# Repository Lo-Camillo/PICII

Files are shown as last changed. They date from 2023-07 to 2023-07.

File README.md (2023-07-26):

# Porta Medicamentos Inteligente
#### Grupo: Aryelle Siqueira, Giselle Pereira e Lohayne Camillo

Muitas pessoas enfrentam dificuldade  para lembrar de tomar seus medicamentos corretamente, especialmente quando têm que tomar múltiplos remédios diariamente.

O porta medicamentos inteligente surge como uma solução para ajudar a superar esses desafios.

## Como funciona?

O porta medicamentos possui 5 compartimentos para armazenar comprimidos. Através de um aplicativo, o usuário pode programar horários específicos para cada remédio, definindo qual compartimento será aberto.

O porta comprimidos possui um modo de programação no qual, ao selecionar um botão, o Wi-Fi será ativado para buscar diretamente do servidor os horários programados no aplicativo.

No horário programado, um alarme tocará, e ao pressionar um botão, o compartimento designado será aberto. Um visor mostrará a quantidade de comprimidos a serem ingeridos. Ao final da ingestão, ao pressionar o botão novamente, o compartimento girará para a próxima posição se houver outro remédio a ser tomado, caso contrário, retornará à posição inicial.

## Software

- [Código fonte e documentação do aplicativo](https://github.com/giselle-lab/porta-comprimidos).

- [Código fonte e documentação da API](https://github.com/AryelleSiqueira/pillbox-api.git).

- [Código fonte e documentação da ESP8266](https://github.com/AryelleSiqueira/porta-medicamentos-esp8266.git).

## Hardware

- [Documentação do hardware do projeto](Hardware_doc).

## Fotos & Vídeos

- [Acessar pasta de fotos e vídeos do projeto](Fotos&Videos).

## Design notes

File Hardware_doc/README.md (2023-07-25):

# Hardware

Para o hardware deste projeto, foi desenvolvida uma placa de circuito impresso em cobre para acomodar os componentes.

## Componentes

Os seguintes componentes foram usados:

- ESP8266 NodeMCU
- Motor de Passo 28BYJ-48 com Driver ULN2003
- Display OLED 0.96″ I2C - 128×64
- L7805C Regulador de Tensão 5V
- Push Button
- 3 resistores de 10k
- Buzzer
- Sockets
- Bateria 9V
- Placa de cobre

## Projeto no Eagle

A imagem a seguir demonstra o esquemático desenvolvido no software Eagle para confecção da placa. 

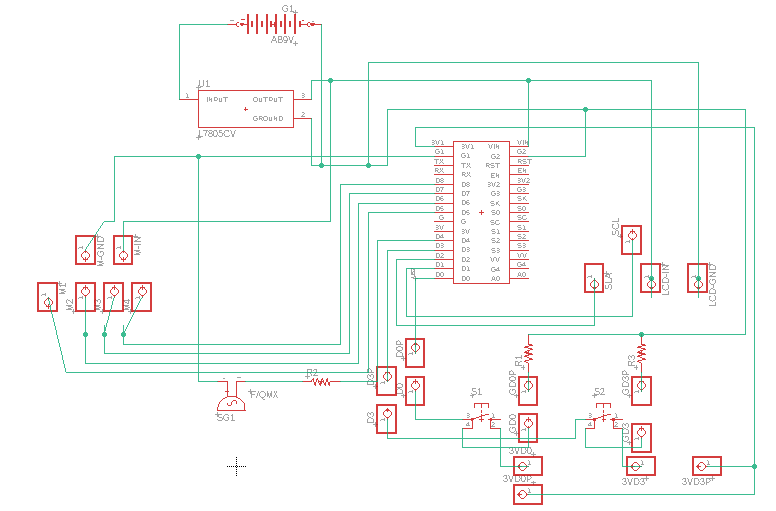
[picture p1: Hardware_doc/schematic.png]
Esquemático


Esta próxima imagem mostra o arquivo Board, onde mostra os componentes em seus respectivos lugares na placa:

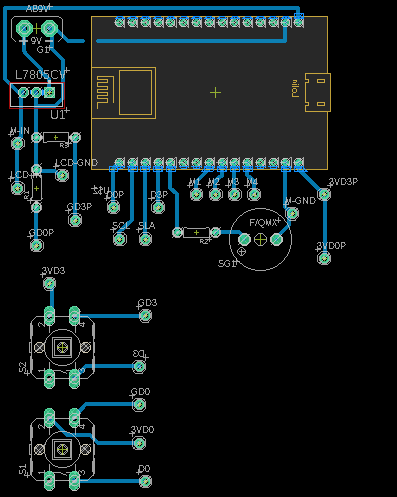
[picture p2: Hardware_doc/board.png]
Board


Alguns detalhes importantes a serem destacados:

- Na caixa desenvolvida, os botões e o visor estão posicionados voltados para fora, o que exigiu que eles fizessem parte de uma placa separada. Portanto, no esquemático, foram inseridos separadores onde, por meio de jumpers, as trilhas poderiam ser conectadas para interligar essas placas. O mesmo conceito se aplica aos conectores do motor.

## Caixa

Para o projeto, foi criada uma caixa em MDF. Na figura a seguir, podemos observar a estrutura dessa caixa.

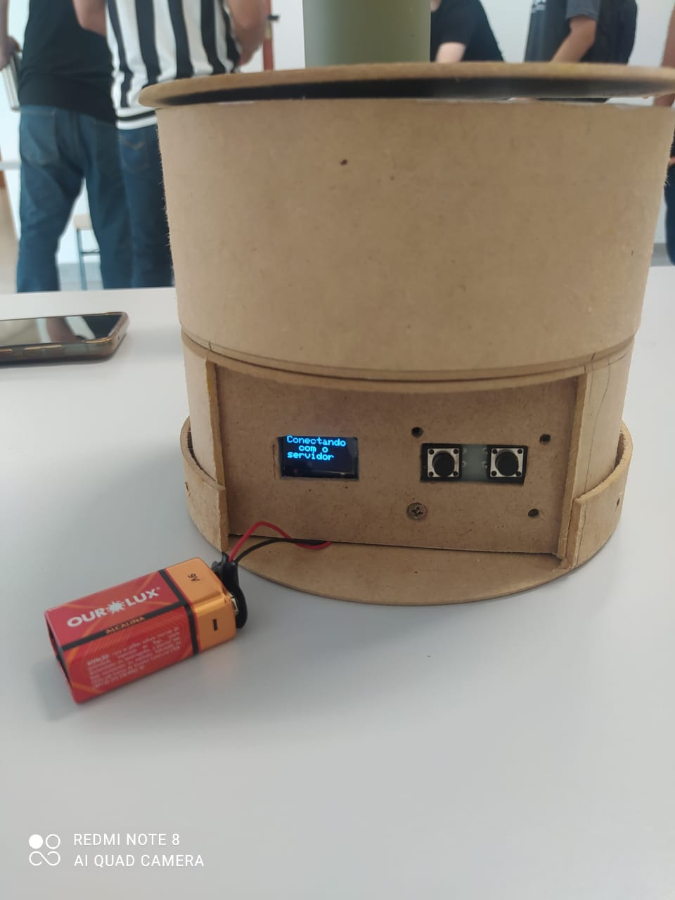
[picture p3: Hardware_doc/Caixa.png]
Caixa


Com o objetivo de acomodar os comprimidos, a parte superior foi dividida em 6 compartimentos, com um deles sempre permanecendo aberto, considerado como a posição inicial do motor.

A parte inferior abriga a placa de circuito impresso desenvolvida, que contém os componentes, bem como os botões e o display estão afixados nessa região.

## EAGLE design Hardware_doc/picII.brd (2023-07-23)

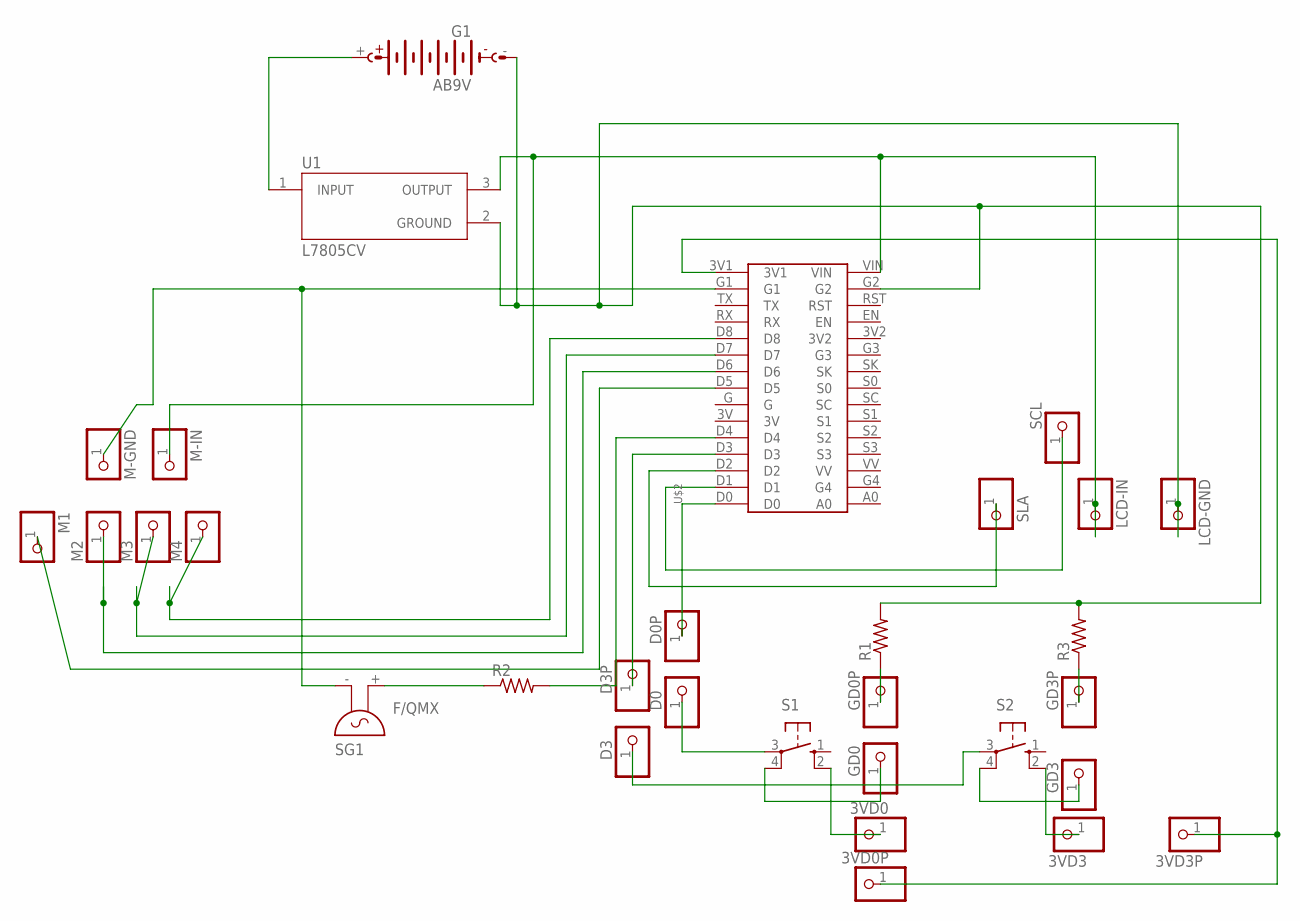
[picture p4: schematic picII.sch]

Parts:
3VD0, 3VD0P, 3VD3, 3VD3P: PINHD-1X1; 1X01
D0, D0P, D3, D3P: PINHD-1X1; 1X01
G1: AB9V
GD0, GD0P, GD3, GD3P: PINHD-1X1; 1X01
LCD-GND: PINHD-1X1; 1X01
LCD-IN: PINHD-1X1; 1X01
M1, M2, M3, M4: PINHD-1X1; 1X01
M-GND: PINHD-1X1; 1X01
M-IN: PINHD-1X1; 1X01
R1, R2, R3: R-US_0204/7; 0204/7
S1, S2: 40-XX; B3F-40XX
SCL: PINHD-1X1; 1X01
SG1: F/QMX
SLA: PINHD-1X1; 1X01
U1: L7805CV; TO255P1040X460X1968-3
U$2: LOLIN

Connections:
unnamed: G1.+, U1.1 (INPUT)
unnamed: R2.1, SG1.+ (2)
unnamed: 3VD0P.1, 3VD3P.1, U$2.3V1
unnamed: M1.1, U$2.D5
unnamed: M2.1, U$2.D6
unnamed: R2.2, U$2.D4
unnamed: GD0.1, S1.4 (P1)
unnamed: SLA.1, U$2.D2
unnamed: SCL.1, U$2.D1
unnamed: M3.1, U$2.D7
unnamed: M4.1, U$2.D8
unnamed: D0.1, S1.3
unnamed: D3.1, S2.3
unnamed: M-GND.1, SG1.- (1), U$2.G1
unnamed: G1.-, LCD-GND.1, R1.2, R3.2, U1.2 (GROUND), U$2.G2
unnamed: GD3.1, S2.4 (P1)
unnamed: LCD-IN.1, M-IN.1, U1.3 (OUTPUT), U$2.VIN
unnamed: GD0P.1, R1.1
unnamed: GD3P.1, R3.1
unnamed: 3VD0.1, S1.2 (S1)
unnamed: 3VD3.1, S2.2 (S1)
unnamed: D0P.1, U$2.D0
unnamed: D3P.1, U$2.D3

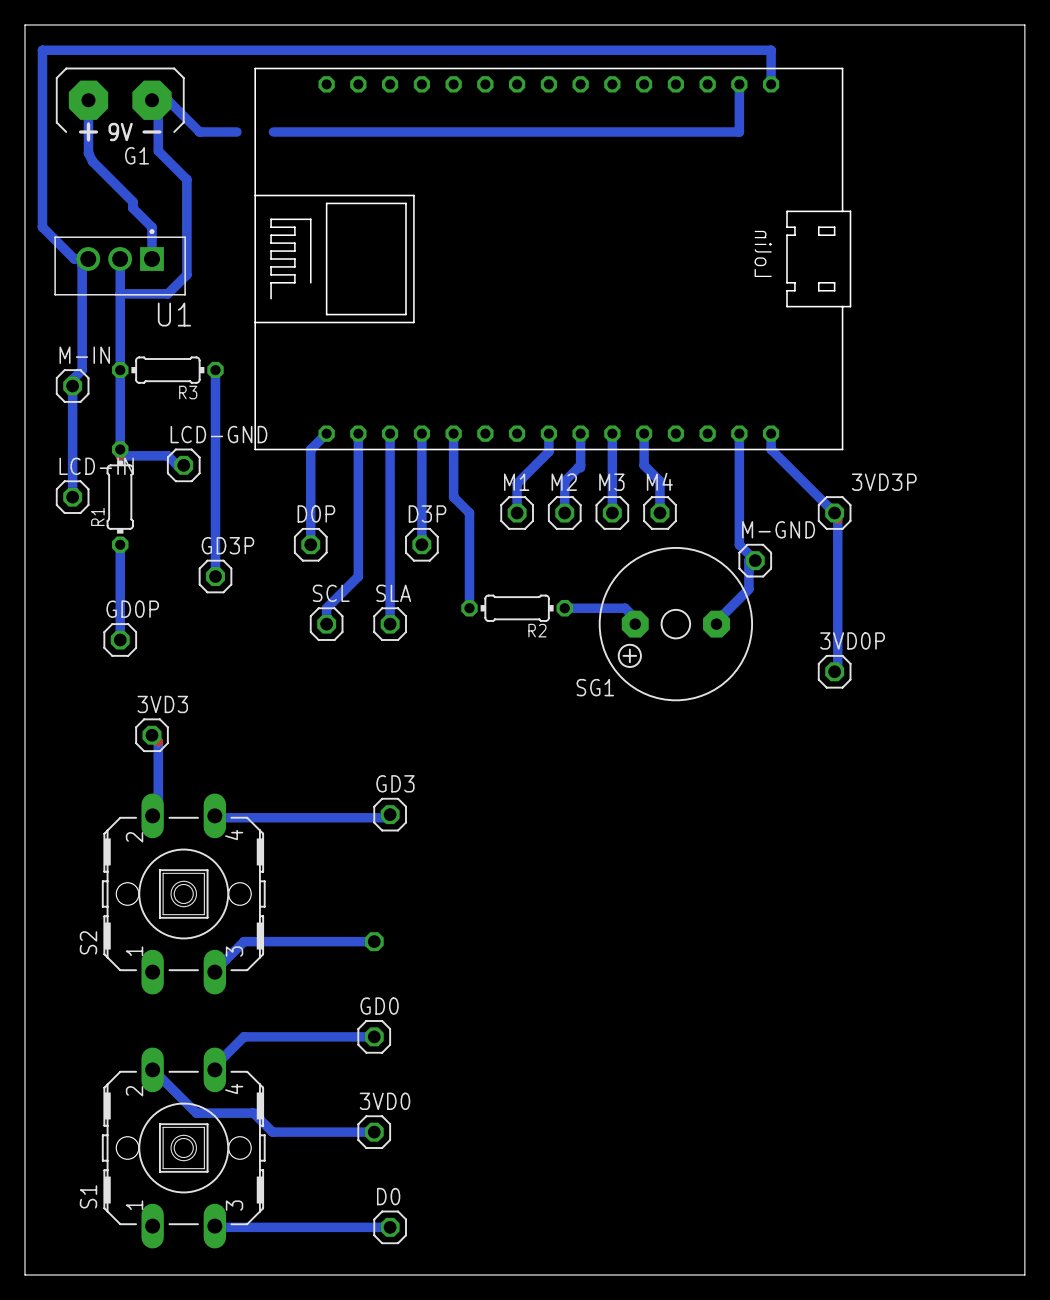
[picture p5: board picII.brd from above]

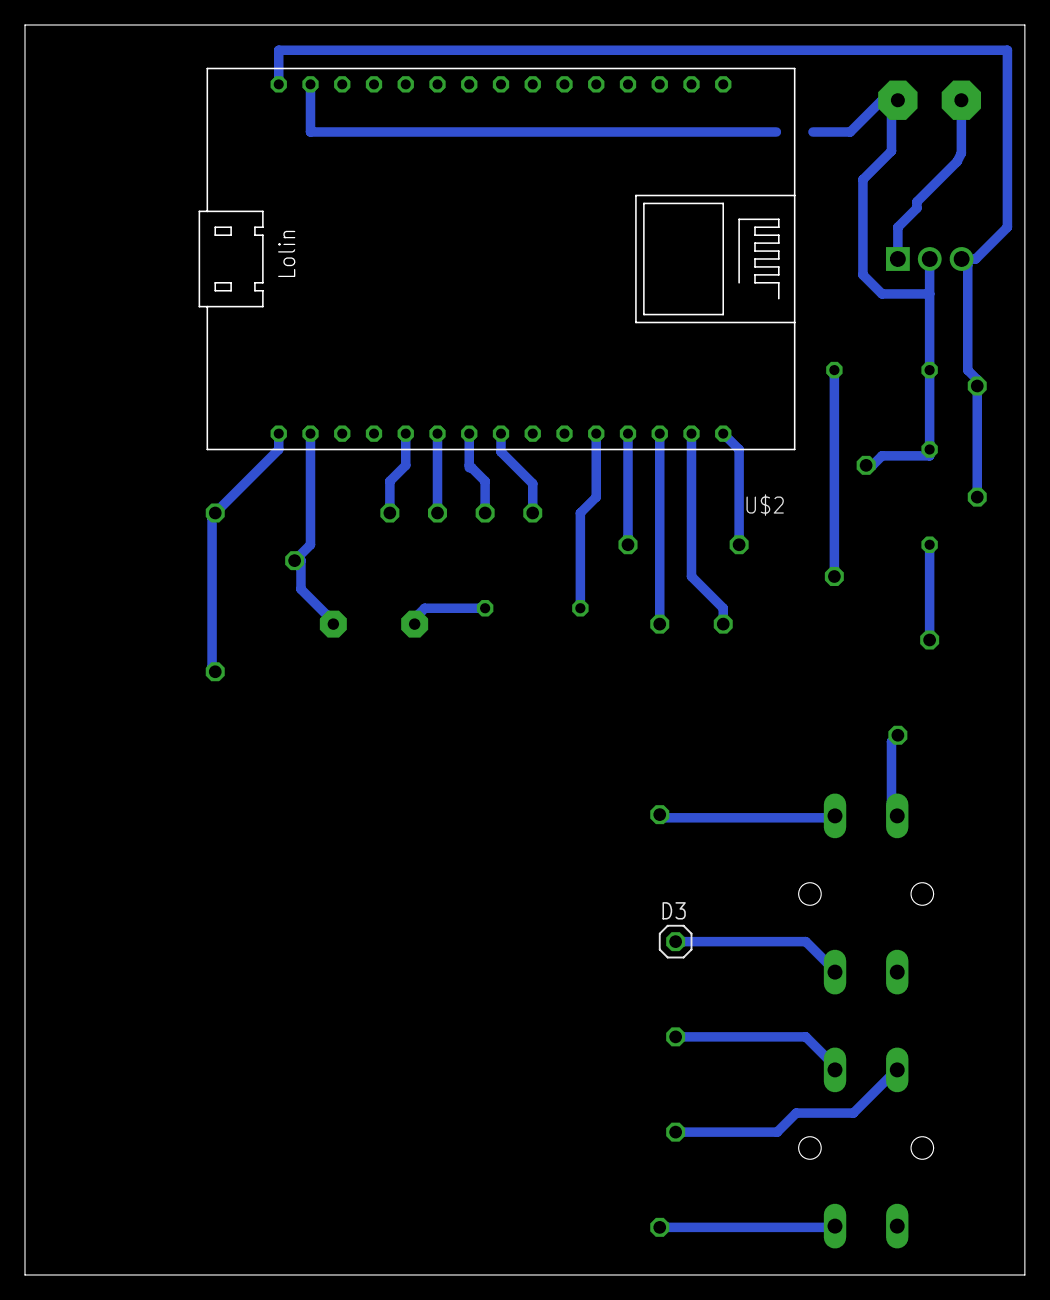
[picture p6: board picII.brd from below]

Board: 2 copper layers, 80.0 x 100.0 mm, 31 parts (2 on the bottom side), 23 nets.
